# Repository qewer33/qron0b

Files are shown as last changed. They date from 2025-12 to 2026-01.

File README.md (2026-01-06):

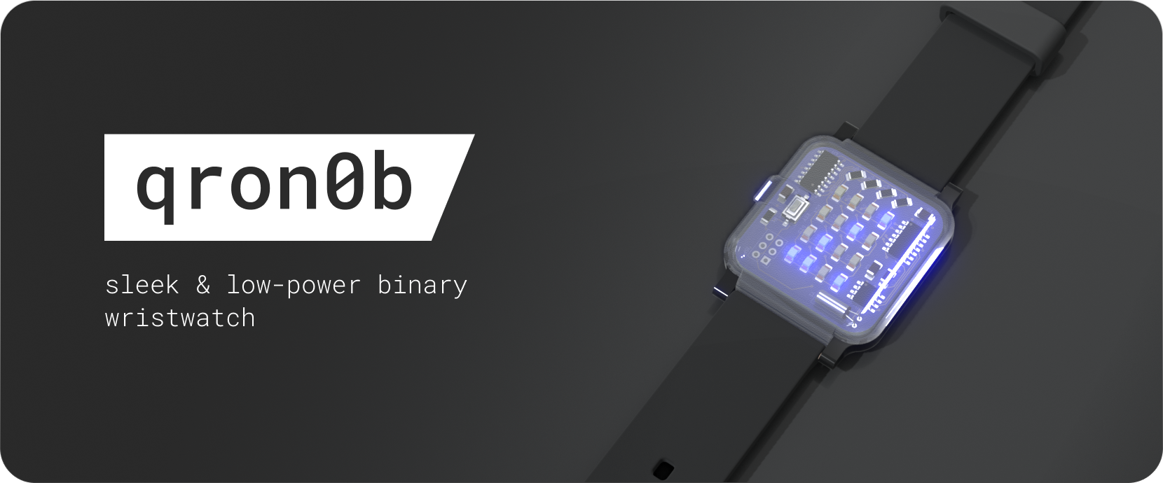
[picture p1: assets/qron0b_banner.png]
banner


**qron0b** is a minimalist and low-power digital **binary wristwatch**. It uses an **Attiny24A/44A/84A as it's MCU**, uses the **DS1302 as it's RTC** and displays the time in **BCD (binary coded decimal)** format with it's integrated **4x4 LED matrix driven by an 74HC595 shift register**. It's powered by a single **CR2032 coin cell battery**. It's designed to use minimal power and **can run without a battery change for months**.

> [!WARNING]  
> This project is NOT perfect by any means, it's my first ever low-power board design and thus contains many design flaws (although mostly small). It does work but build it at your own risk and definitely don't expect everything to go smoothly.

## Repository Layout
- [pcb/](https://github.com/qewer33/qron0b/tree/main/pcb): The KiCAD project for the qron0b PCB.
- [cad/](https://github.com/qewer33/qron0b/tree/main/cad): The FreeCAD files (and .stl + .step for 3D printing) for the watch case.
- [firmware/](https://github.com/qewer33/qron0b/tree/main/firmware): The source code for the qron0b firmware, written in bare metal AVR C.
- [assets/](https://github.com/qewer33/qron0b/tree/main/assets) Screenshots and render files used in the README.

## The Product

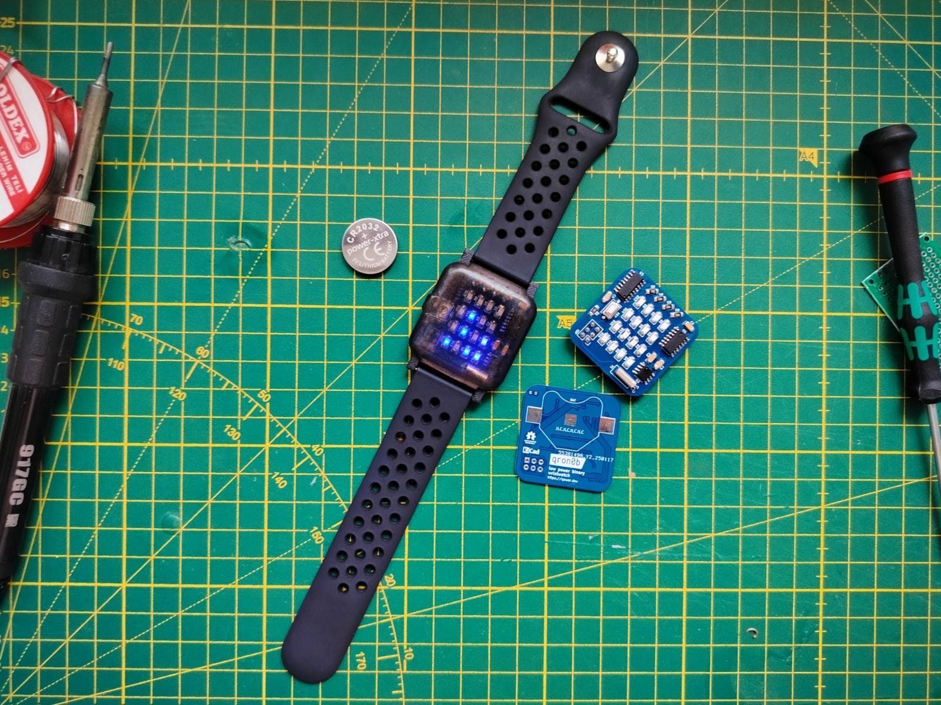
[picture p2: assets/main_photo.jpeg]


### Features

qron0b's default firmware is very minimalistic and thus only contains two basic features: **reading time** and **setting time**. The watch is in the sleep state by default with the CPU in power-down mode and the display off. When the onboard button is clicked, the CPU is wakes up from sleep and displays the current time in the LED matrix for 10 seconds. The time can be set while the watch is awake by long pressing the onboard button. Both features are explained in detail under the next two headings.

### Reading Time

The time is displayed in BCD (binary coded decimal) format on qron0b's 4x4 LED matrix in columns (HH:MM), with the LSB (least-significant bit) being the bottom-most LED. Meaning for each column; the bottom-most LED represents 1, the one above represents 2, two above represents 4 and the top-most LED represents 8. All LEDs being off in a column represents 0. The first column is the tens digit of hour, the second column is the ones digit of hour, third column is the tens digit of minute and the fourth column is the ones digit of minute.

Below is a visual explanation and a few examples to help explain it better:

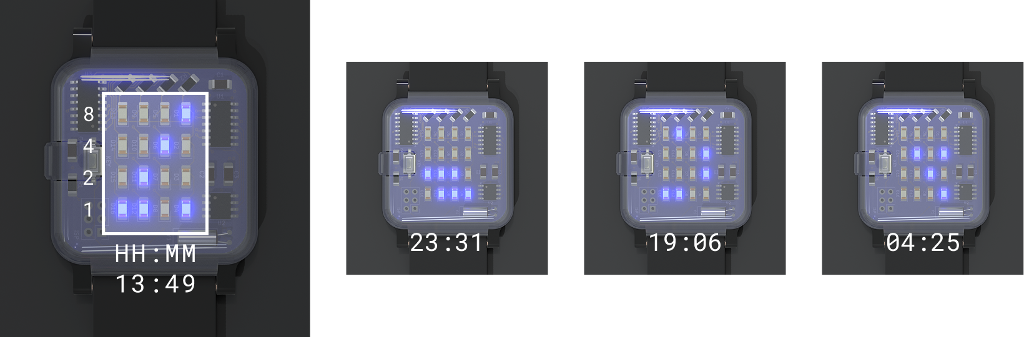
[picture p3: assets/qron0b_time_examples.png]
reading time


### Setting Time

The time can be set while the watch is awake by long pressing the onboard button. The whole LED matrix will flash for ~0.5 seconds to indicate entering edit mode. After the watch enters edit mode, the first column (tens digit of hour) will start flashing (it may not flash if it's 0). Press the button once to increment the current column/digits value (it will wrap automatically, eg. between 0-2 for tens digit of hour or 0-5 for the tens digit of minute). After setting the current digit to the desired value, long press the button to move on to the next digit (the next column will start flashing). Long pressing on the last digit/column (the ones column of minute) will save the newly set time to the RTC and exit edit mode.

## Hardware

### PCB Design

The qron0b PCB is designed in the free and open source EDA software, KiCAD. You can find the PCB design source files under [pcb/](https://github.com/qewer33/qron0b/tree/main/pcb).

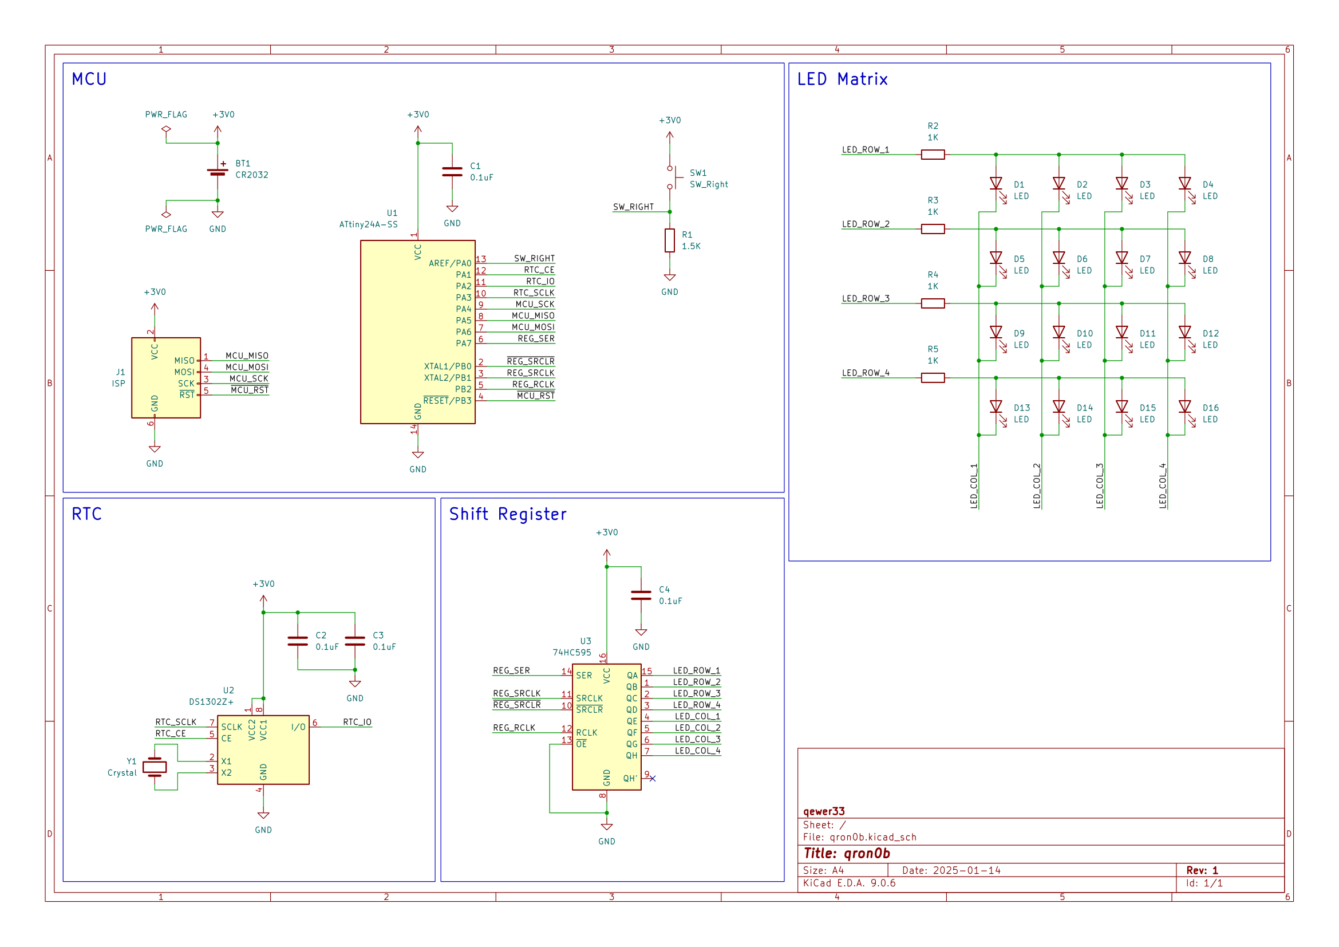
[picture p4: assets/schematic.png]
schematic


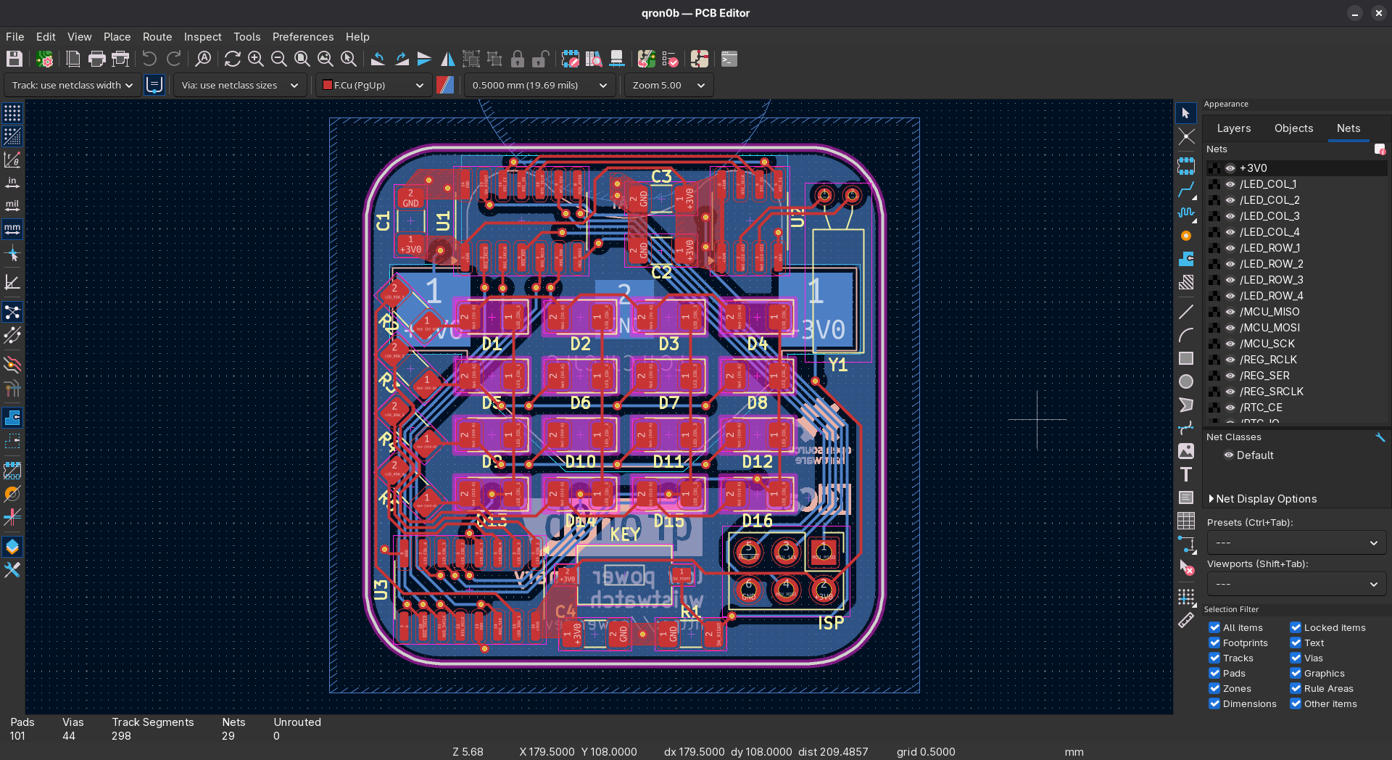
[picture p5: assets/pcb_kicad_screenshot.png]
kicad screenshot


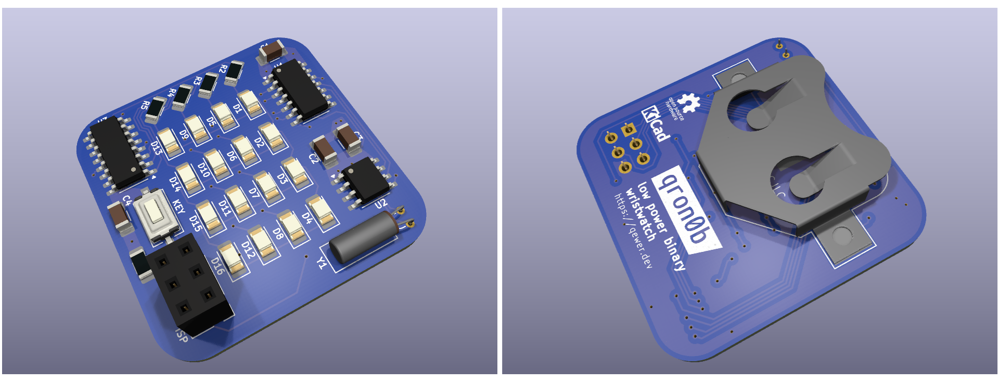
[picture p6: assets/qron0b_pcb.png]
pcb 3d render


### Mechanical Design

The mechanical parts of qron0b (the watch casing) is designed in the free and open source CAD software, FreeCAD. The watch case is designed in 2 parts: the bottom base and the top "glass". They connect together via a simple clip system. The bottom base casing accepts 22mm GT2/GT3 style watch straps.

You can find the CAD source and 3D print files under [cad/](https://github.com/qewer33/qron0b/tree/main/cad).

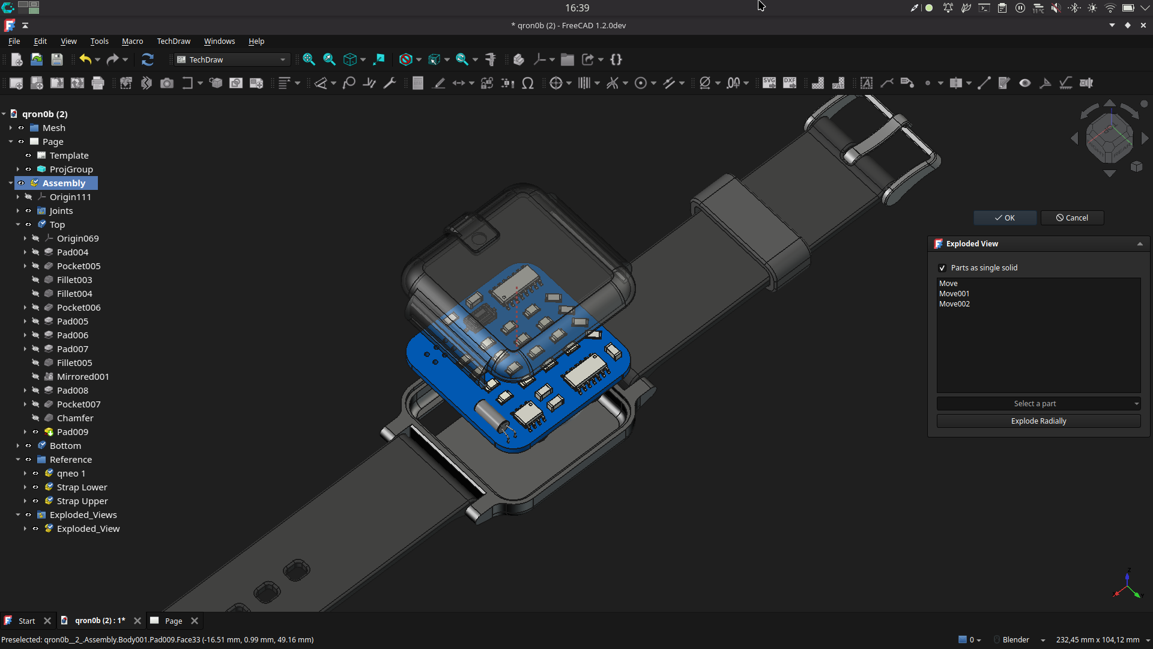
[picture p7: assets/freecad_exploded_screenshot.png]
freecad screenshot


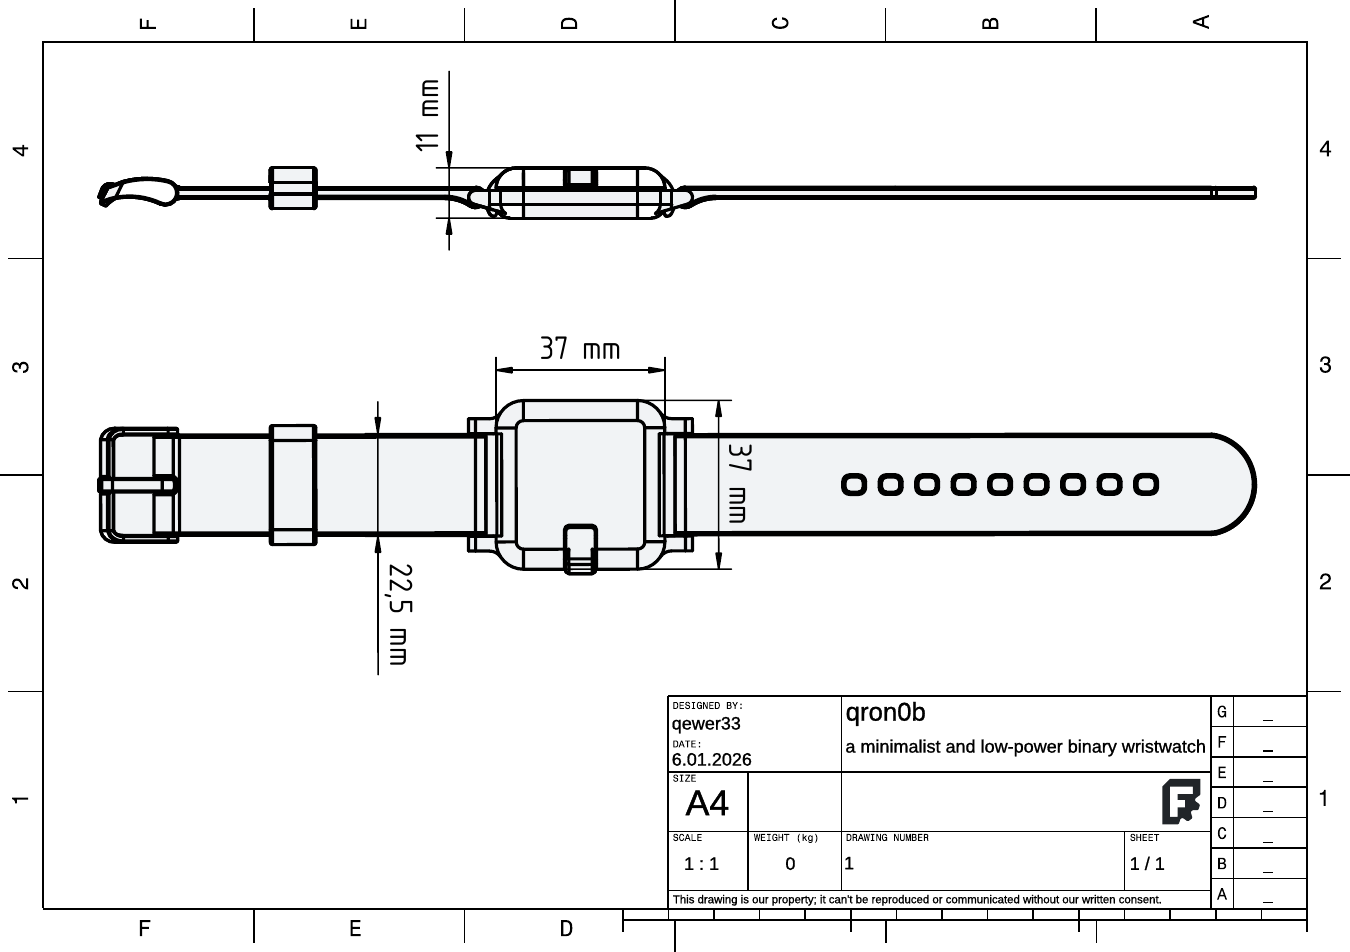
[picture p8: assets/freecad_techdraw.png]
technical drawing


## Firmware

The qron0b firmware is written in bare-metal AVR C. It's written to be as minimal as possible and is only 1916 bytes, meaning it can even run on the ATtiny24A (in fact, it's designed for the 24A!).

For more information on the firmware, see the README.md file inside [firmware/](https://github.com/qewer33/qron0b/tree/main/firmware).

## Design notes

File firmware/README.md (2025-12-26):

# Firmware Architecture

- `main.c`: The main source file, contains firmware entry point and main firmware logic.
- `config.h`: Contains global pin definition macros.
- `gpio.h`: Contains helper GPIO macros.
- `init.h/c`: Contains the startup and initilization routine functions.
- `key.h/c`: Contains functions and definitions related to the onboard button input.
- `matrix.h/c`: Contains shift register read/write functions and higher-level matrix screen interface functions.
- `rtc.h/c`: Contains RTC read/write functions.

# Programming

The qron0b board can be programmed with any AVR ISP programmer (including any AVR Arduino board via Arduino as ISP). You need to have the `avr-gcc` toolchain installed. If you're on Linux, you can use the provided shell scripts to build and flash the firmware.

Use the `make` command to build & flash the firmware. Build artifacts (`.elf`, `.hex` and `.o` files) will be generated in the `build/` directory. Use the `make flash_fuses` command in first flash to set the correct fuses. If programming with Arduino as ISP, put a 10uF cap between the Arduino's RES and GND pins.

```sh
# Build the firmware
make

# Flash firmware and fuses to USB0 (do this for first time flashing!)
make flash_fuses
# Flash firmware only to USB0 (do this after first flash)
make flash

# Specify a different port for flashing
make flash PORT=USB1

# See firmware size
make size

# Clean the build directory
make clean
```

Alternatively, you can also use the provided bash scripts:

Use the provided `build.sh` script to compile & build the firmware.

Use the provided `flasn.sh` script to flash with an Arduino as ISP mounted at USB0 (change the port inside the script if necessary). Use the `--fuses` option in first flash to set the correct fuses.

```sh
# Build the firmware
./build.sh

# Flash the firmware with fuses (do this for first time flashing!)
./flash.sh --fuses
# Flash the firmware without fuses (do this after first flash)
./flash.sh

# Build and flash firmware
./build.sh && ./flash.sh
```

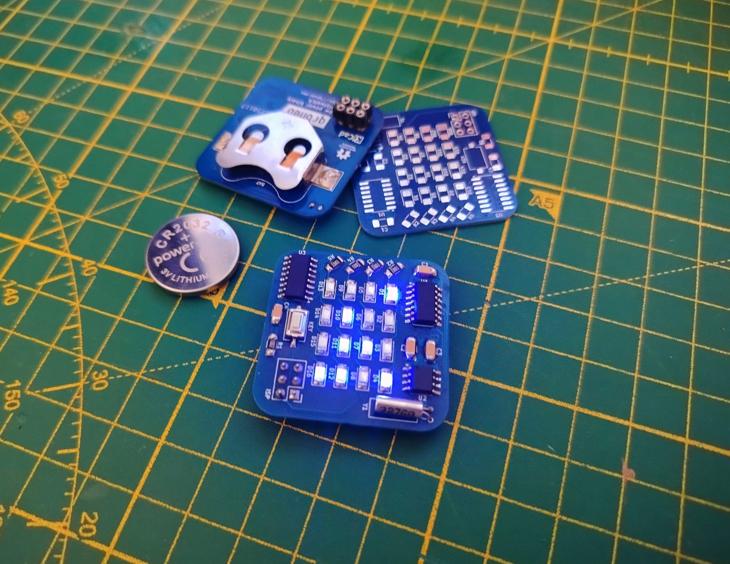
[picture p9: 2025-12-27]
assets/board_photo.jpeg

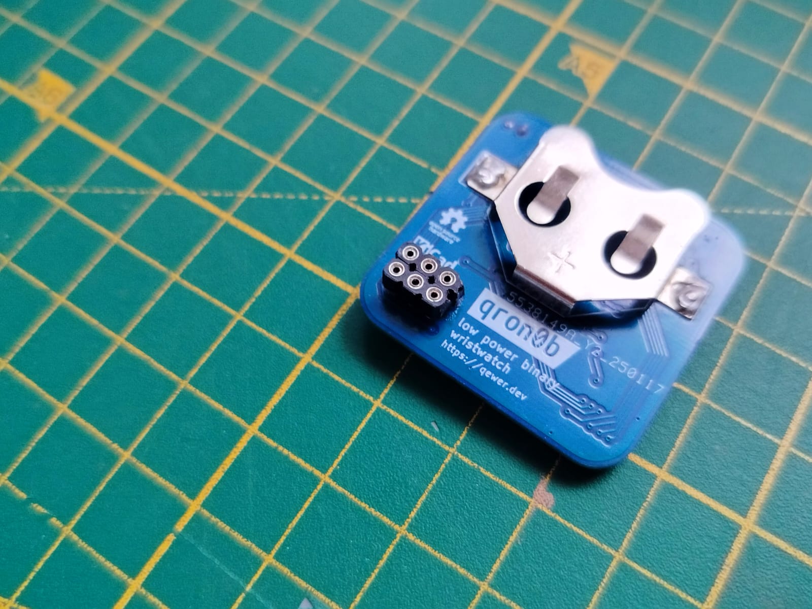
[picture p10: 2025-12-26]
assets/programming_header_photo.jpeg

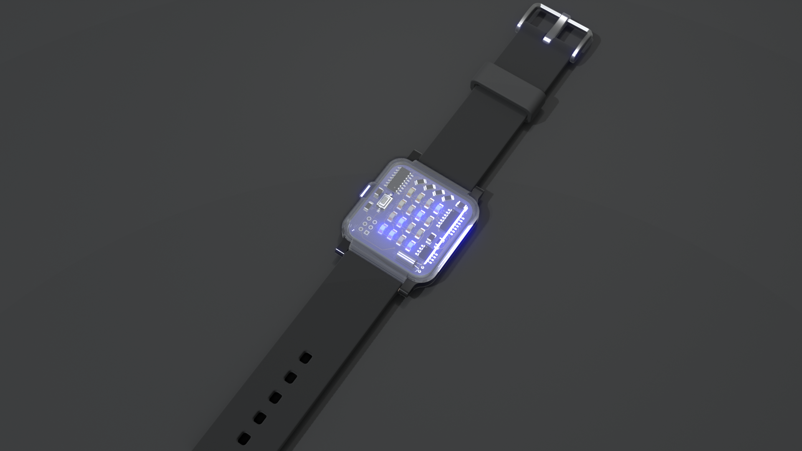
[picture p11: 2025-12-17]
assets/qron0b_render.png

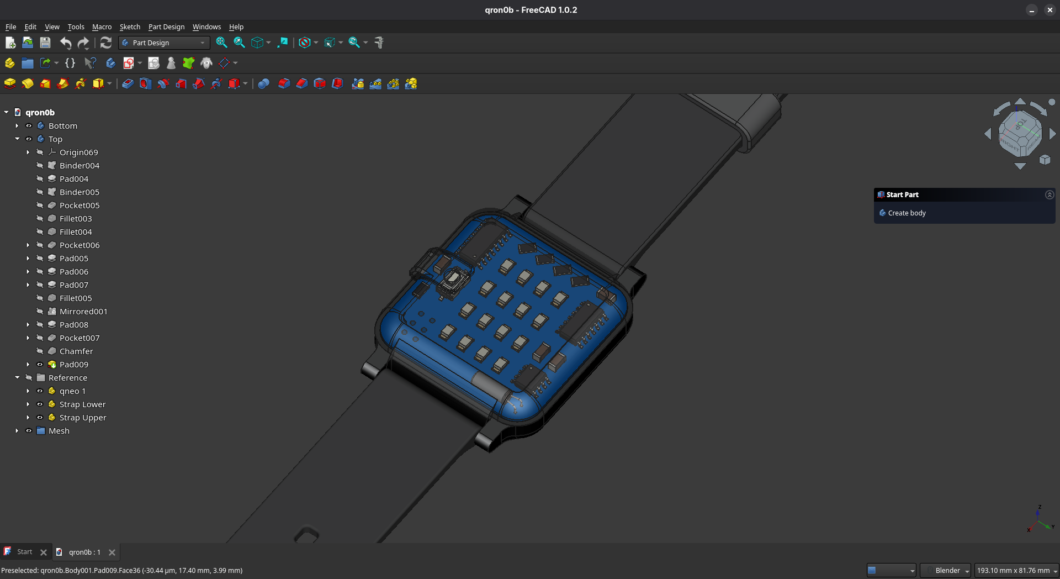
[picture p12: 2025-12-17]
assets/freecad_screenshot.png

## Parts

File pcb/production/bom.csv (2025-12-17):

Designator | Footprint | Quantity | Value | LCSC Part #
BAT | BatteryHolder_Multicomp_BC-2001_1x2032 | 1 | CR2032
C1, C2, C3, C4 | 1206 | 4 | 0.1uF
D1, D10, D11, D12, D13, D14, D15, D16, D2, D3, D4, D5, D6, D7, D8, D9 | 1206 | 16 | LED
ISP | PinHeader_2x03_P2.54mm_Vertical | 1 | ISP
KEY | SW_Tactile_SPST_NO_Straight_CK_PTS636Sx25SMTRLFS | 1 | SW_Right
R1 | 1206 | 1 | 1.5K
R2, R3, R4, R5 | 1206 | 4 | 1K
U1 | SOIC-14_3.9x8.7mm_P1.27mm | 1 | ATtiny24A-SS
U2 | SOIC-8_3.9x4.9mm_P1.27mm | 1 | DS1302Z+
U3 | SOIC-16_3.9x9.9mm_P1.27mm | 1 | 74HC595
Y1 | Crystal_C38-LF_D3.0mm_L8.0mm_Horizontal | 1 | Crystal

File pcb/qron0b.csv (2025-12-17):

Id | Designator | Footprint | Quantity | Designation | Supplier and ref
1 | SW1 | SW_Tactile_SPST_NO_Straight_CK_PTS636Sx25SMTRLFS | 1 | SW_Right
2 | R4,R3,R2,R5 | R_1206_3216Metric_Pad1.30x1.75mm_HandSolder | 4 | 1K
3 | D8,D13,D15,D1,D2,D11,D12,D6,D16,D9,D14,D3,D7,D10,D5,D4 | LED_1206_3216Metric_Pad1.42x1.75mm_HandSolder | 16 | LED
4 | U3 | SOIC-16_3.9x9.9mm_P1.27mm | 1 | 74HC595
5 | C3,C1,C4,C2 | C_1206_3216Metric_Pad1.33x1.80mm_HandSolder | 4 | 0.1uF
6 | U1 | SOIC-14_3.9x8.7mm_P1.27mm | 1 | ATtiny24A-SS
7 | U2 | SOIC-8_3.9x4.9mm_P1.27mm | 1 | DS1302Z+
8 | R1 | R_1206_3216Metric_Pad1.30x1.75mm_HandSolder | 1 | 1.5K

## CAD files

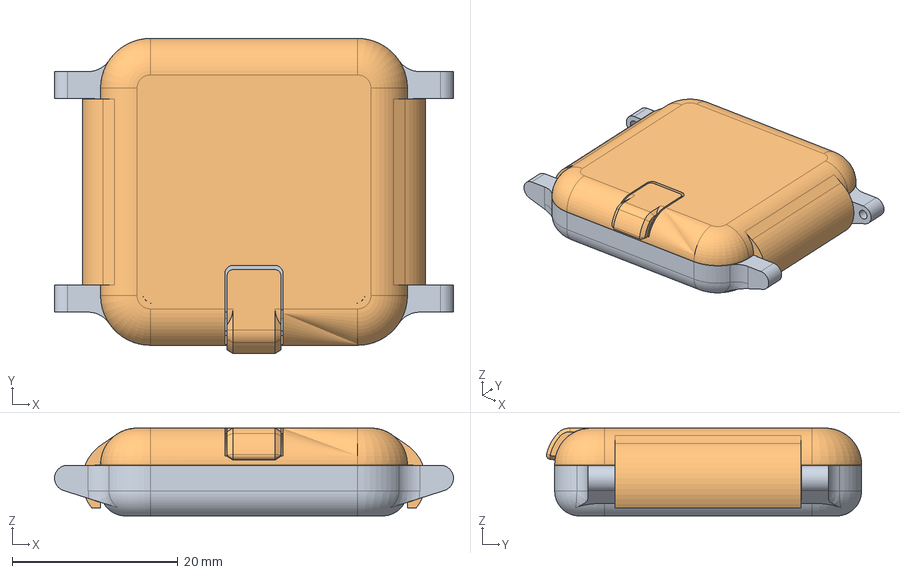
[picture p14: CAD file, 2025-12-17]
cad/qron0b.FCStd
48.1 x 38.0 x 10.6 mm
Bottom
Top

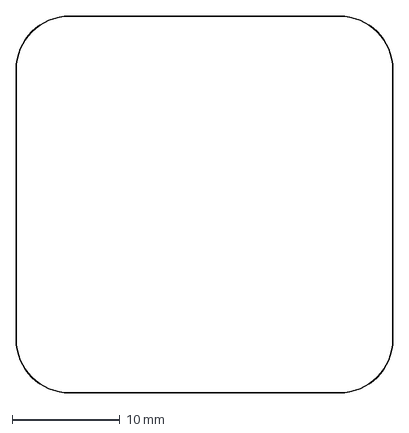
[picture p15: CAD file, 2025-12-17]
pcb/board_outline.dxf
35.0 x 35.0 mm

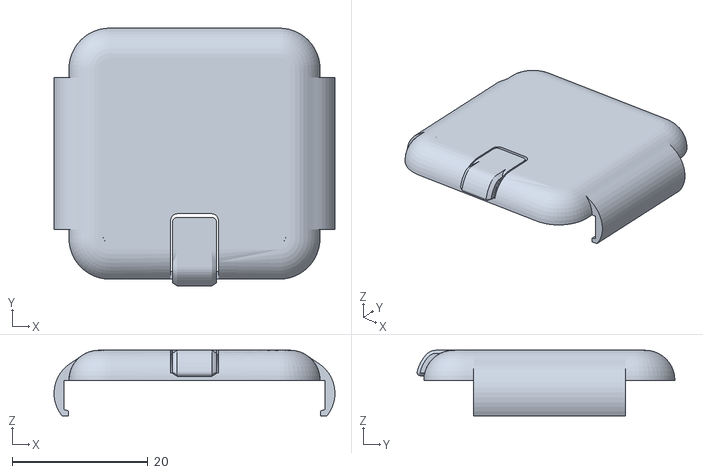
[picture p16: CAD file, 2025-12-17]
cad/qron0b-TopGlass.stl
41.4 x 38.0 x 9.67

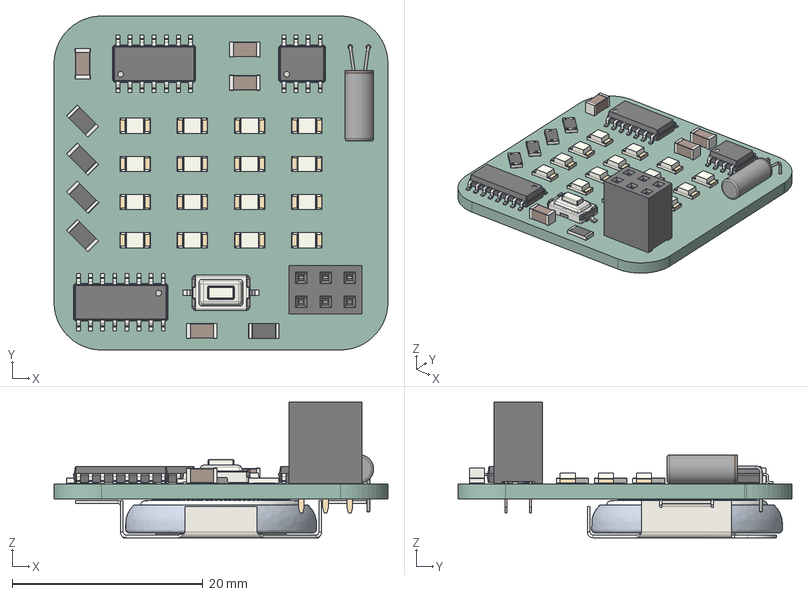
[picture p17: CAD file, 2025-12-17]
pcb/qron0b.step
35.0 x 35.0 x 14.2 mm
PTS636Sx25SMTRLFS
R_1206_3216Metric x 5
LED_1206_3216Metric x 16
SOIC_16_39x99mm_P127mm
PinSocket_2x03_P2.54mm_Vertical
C_1206_3216Metric x 4
SOIC_14_39x87mm_P127mm
C38_LF_Horizontal
SOIC_8_39x49mm_P127mm
RS_PRO_CR2032_CLIP_2378333 v5
Document
_autosave-qneo_PCB

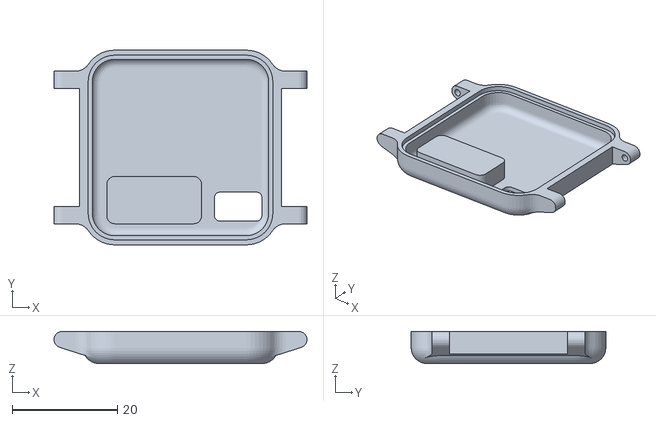
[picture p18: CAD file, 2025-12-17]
cad/qron0b-Bottom.stl
48.1 x 37.0 x 6.10

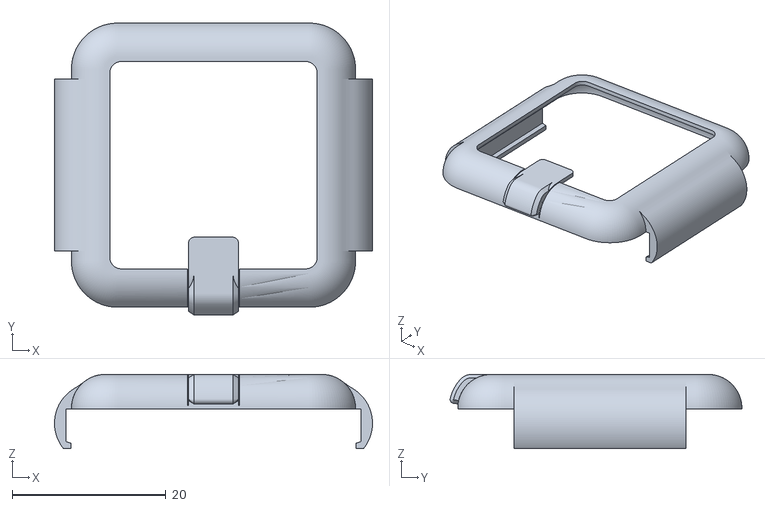
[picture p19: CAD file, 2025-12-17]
cad/qron0b-Top.stl
41.4 x 38.0 x 9.67

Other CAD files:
assets/qron0b.blend

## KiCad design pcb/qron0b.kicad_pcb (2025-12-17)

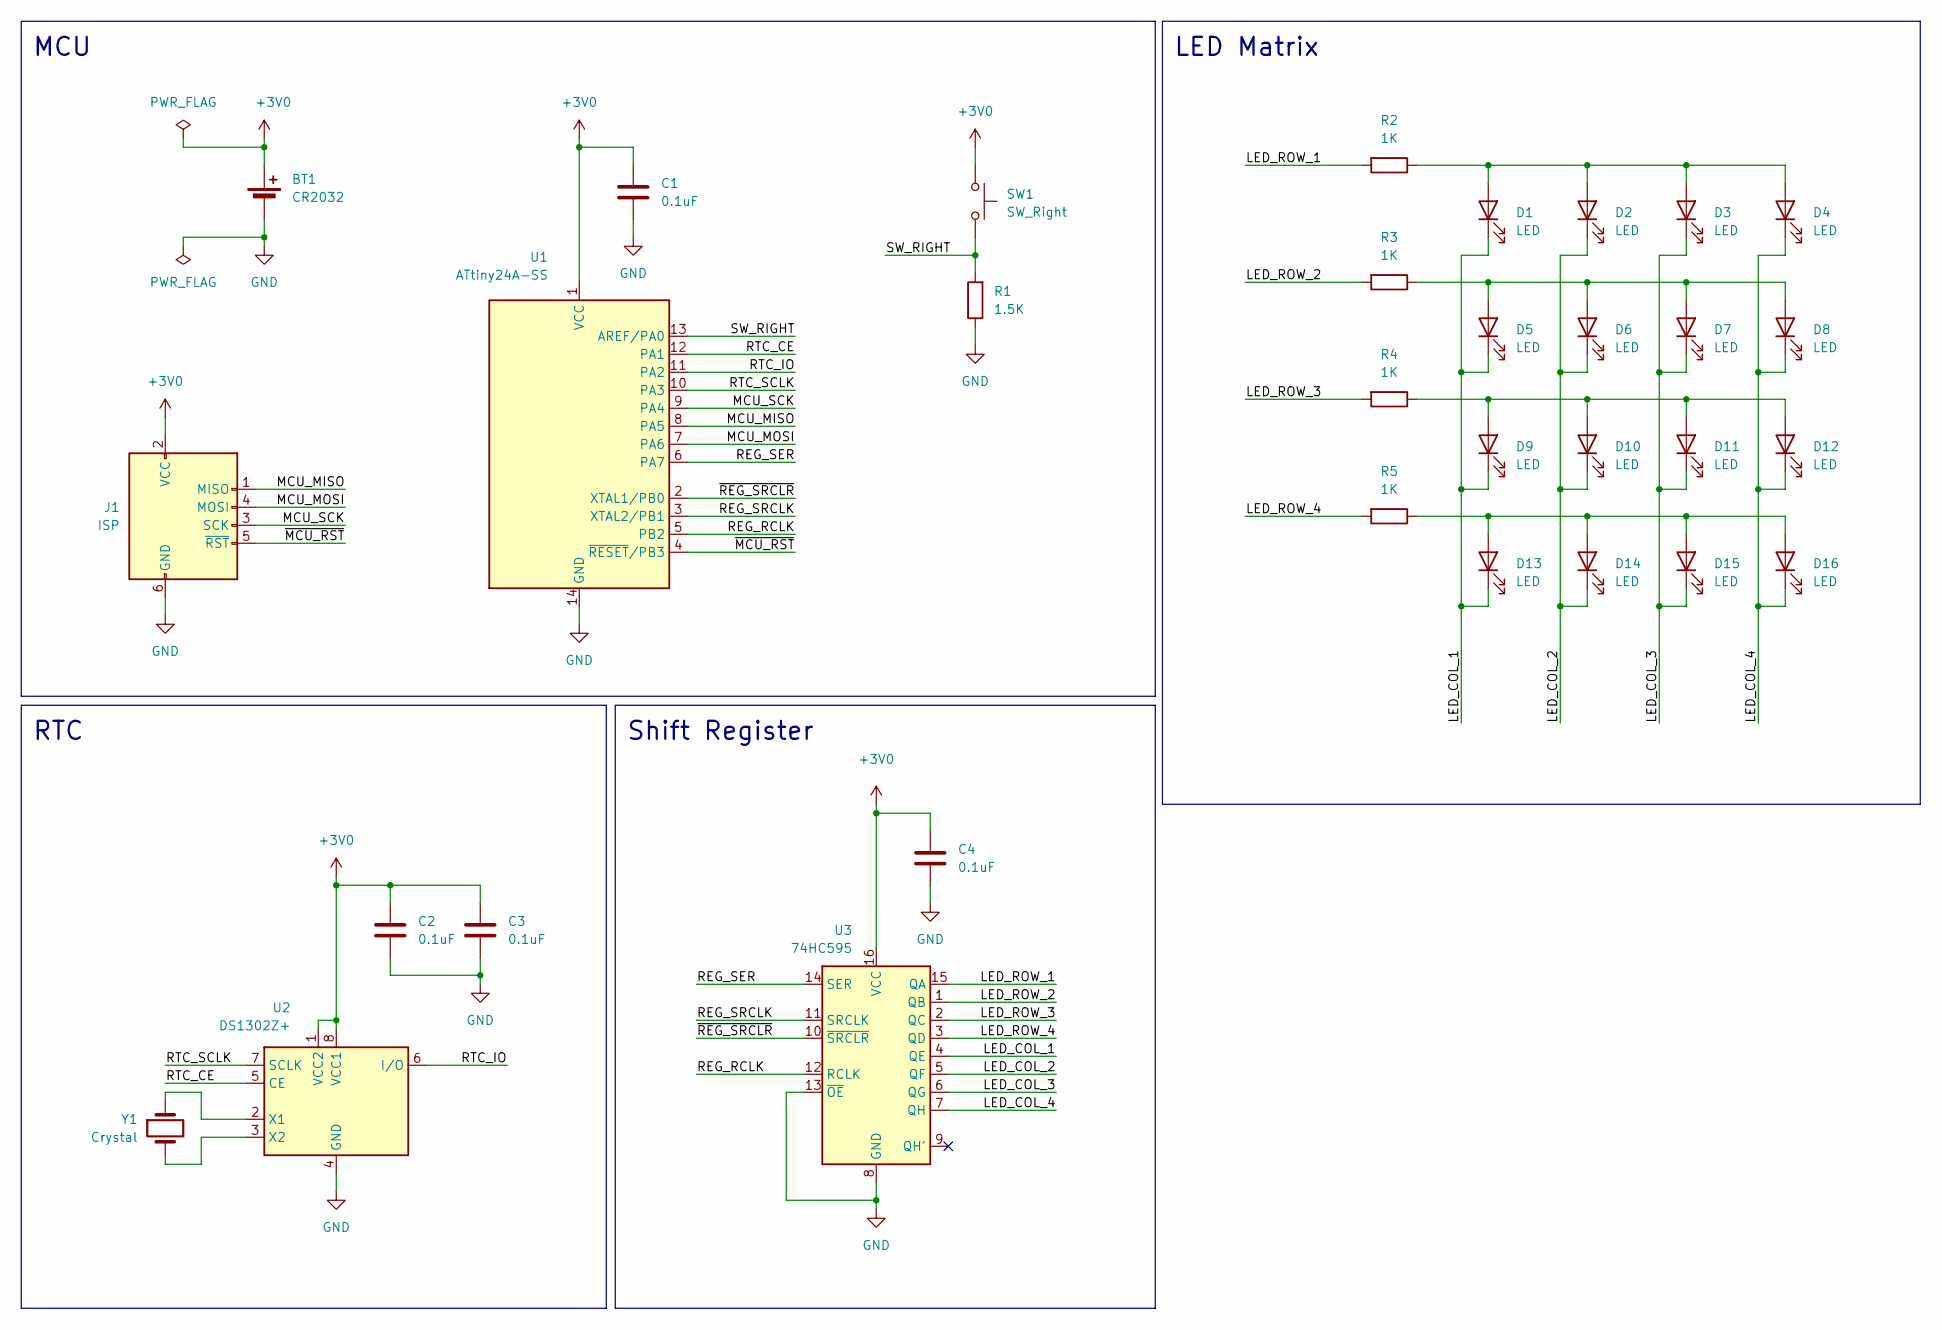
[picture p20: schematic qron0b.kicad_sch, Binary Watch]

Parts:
BT1: CR2032; BatteryHolder_Multicomp_BC-2001_1x2032
C1, C2, C3, C4: 0.1uF; C_1206_3216Metric_Pad1.33x1.80mm_HandSolder
D1, D2, D3, D4, D5, D6, D7, D8, D9, D10, D11, D12, D13, D14, D15, D16: LED; LED_1206_3216Metric_Pad1.42x1.75mm_HandSolder
J1: ISP; PinHeader_2x03_P2.54mm_Vertical
R1: 1.5K; R_1206_3216Metric_Pad1.30x1.75mm_HandSolder
R2, R3, R4, R5: 1K; R_1206_3216Metric_Pad1.30x1.75mm_HandSolder
SW1: SW_Right; SW_Tactile_SPST_NO_Straight_CK_PTS636Sx25SMTRLFS
U1: ATtiny24A-SS; SOIC-14_3.9x8.7mm_P1.27mm
U2: DS1302Z+; SOIC-8_3.9x4.9mm_P1.27mm
U3: 74HC595; SOIC-16_3.9x9.9mm_P1.27mm
Y1: Crystal; Crystal_C38-LF_D3.0mm_L8.0mm_Horizontal

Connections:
+3V0: BT1.1 (+), C1.1, C2.1, C3.1, C4.1, J1.2 (VCC), SW1.2, U1.1 (VCC), U2.1 (VCC2), U2.8 (VCC1), U3.16 (VCC); also elsewhere on the board
/LED_COL_1: D1.1 (K), D5.1 (K), D9.1 (K), D13.1 (K), U3.4 (QE)
/LED_COL_2: D2.1 (K), D6.1 (K), D10.1 (K), D14.1 (K), U3.5 (QF)
/LED_COL_3: D3.1 (K), D7.1 (K), D11.1 (K), D15.1 (K), U3.6 (QG)
/LED_COL_4: D4.1 (K), D8.1 (K), D12.1 (K), D16.1 (K), U3.7 (QH)
/LED_ROW_1: R2.2, U3.15 (QA)
/LED_ROW_2: R3.2, U3.1 (QB)
/LED_ROW_3: R4.2, U3.2 (QC)
/LED_ROW_4: R5.2, U3.3 (QD)
/MCU_MISO: J1.1 (MISO), U1.8 (PA5); also elsewhere on the board
/MCU_MOSI: J1.4 (MOSI), U1.7 (PA6); also elsewhere on the board
/MCU_SCK: J1.3 (SCK), U1.9 (PA4); also elsewhere on the board
/REG_RCLK: U1.5 (PB2), U3.12 (RCLK)
/REG_SER: U1.6 (PA7), U3.14 (SER)
/REG_SRCLK: U1.3 (XTAL2/PB1), U3.11 (SRCLK)
/RTC_CE: U1.12 (PA1), U2.5 (CE)
/RTC_IO: U1.11 (PA2), U2.6 (I/O)
/RTC_SCLK: U1.10 (PA3), U2.7 (SCLK)
/SW_RIGHT: R1.2, SW1.1, U1.13 (AREF/PA0); also elsewhere on the board
/~MCU_RST: J1.5 (~RST), U1.4 (~RESET/PB3); also elsewhere on the board
/~REG_SRCLR: U1.2 (XTAL1/PB0), U3.10 (~SRCLR)
GND: BT1.2 (-), C1.2, C2.2, C3.2, C4.2, J1.6 (GND), R1.1, U1.14 (GND), U2.4 (GND), U3.8 (GND), U3.13 (~OE); also elsewhere on the board
unnamed: D1.2 (A), D2.2 (A), D3.2 (A), D4.2 (A), R2.1
unnamed: D5.2 (A), D6.2 (A), D7.2 (A), D8.2 (A), R3.1
unnamed: D9.2 (A), D10.2 (A), D11.2 (A), D12.2 (A), R4.1
unnamed: D13.2 (A), D14.2 (A), D15.2 (A), D16.2 (A), R5.1
unnamed: U2.2 (X1), Y1.1
unnamed: U2.3 (X2), Y1.2

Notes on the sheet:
Shift Register
MCU
LED Matrix
RTC

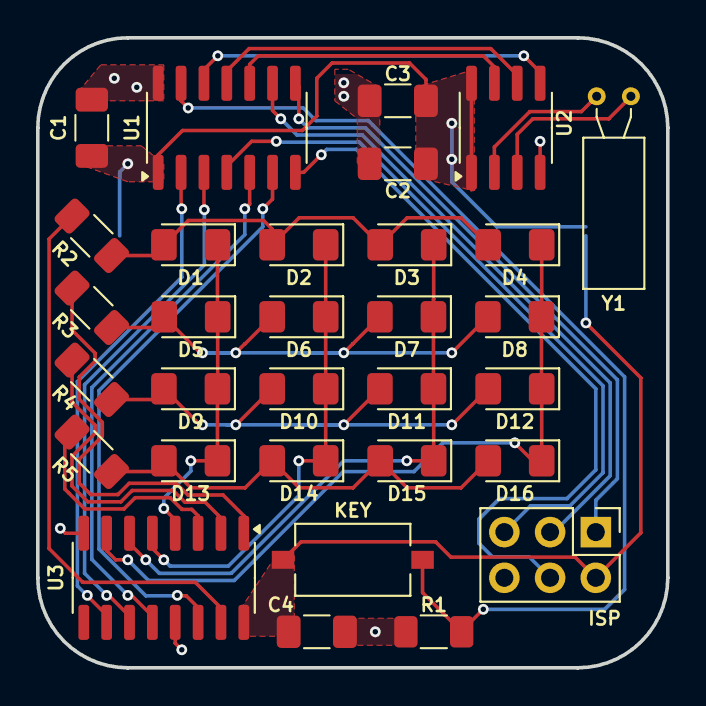
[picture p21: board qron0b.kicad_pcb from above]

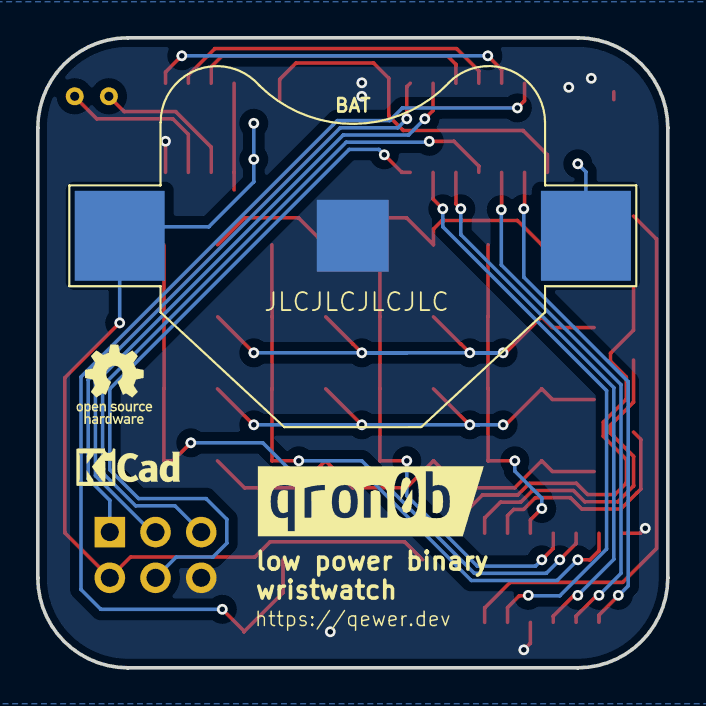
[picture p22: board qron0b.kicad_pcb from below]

Board: 2 copper layers, 35.0 x 35.0 mm, 33 parts (2 on the bottom side), 28 nets.

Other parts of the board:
BAT: CR2032; BatteryHolder_Multicomp_BC-2001_1x2032
ISP: ISP; PinHeader_2x03_P2.54mm_Vertical
KEY: SW_Right; SW_Tactile_SPST_NO_Straight_CK_PTS636Sx25SMTRLFS
kibuzzard-678832A4: G***; kibuzzard-678832A4

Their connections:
+3V0: BAT.1 (+), ISP.2 (VCC), KEY.2; also elsewhere on the board
/MCU_MISO: ISP.1 (MISO); also elsewhere on the board
/MCU_MOSI: ISP.4 (MOSI); also elsewhere on the board
/MCU_SCK: ISP.3 (SCK); also elsewhere on the board
/SW_RIGHT: KEY.1; also elsewhere on the board
/~MCU_RST: ISP.5 (~RST); also elsewhere on the board
GND: BAT.2 (-), ISP.6 (GND); also elsewhere on the board

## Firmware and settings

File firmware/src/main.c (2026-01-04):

#include "init.h"
#include "matrix.h"
#include "rtc.h"
#include "key.h"

#include <avr/eeprom.h>
#include <avr/io.h>
#include <avr/interrupt.h>
#include <util/delay.h>
#include <avr/wdt.h>

// Flag to set comptime only on first boot after flash
#define COMPTIME_FLAG_ADDR 0x00

// Global variable to track system uptime (in ms)
volatile uint16_t uptime = 0;

// Watch state management
typedef enum {
    STATE_DISPLAY,
    STATE_EDIT
} State;

static State state = STATE_DISPLAY;
static uint8_t h, m, s;

// Edit mode management
typedef enum {
    EDIT_HOUR_TENS,
    EDIT_HOUR_ONES,
    EDIT_MINUTE_TENS,
    EDIT_MINUTE_ONES,
} EditMode;

static EditMode edit_mode = EDIT_HOUR_TENS;
static uint8_t edit_h = 0;
static uint8_t edit_m = 0;
static void state_display(void);
static void state_edit(KeyEvent key_ev);

int main(void) {
    MCUSR = 0;
    wdt_disable();
        
    // Hardware init
    disable_unused();
    setup_wakeup_pin();
    shift_register_init();
    rtc_init();
    timer_init();
    
    // Enable watchdog timer
    wdt_enable(WDTO_2S);

    sei(); // Enable interrupts

    // Use compile time clock only after first flash
    if (eeprom_read_byte(COMPTIME_FLAG_ADDR) == 0xFF) {
        get_compile_time(&h, &m, &s);
        rtc_set_time(h, m, s);
        // Update flag
        eeprom_update_byte(COMPTIME_FLAG_ADDR, 0x00);
    }

    wdt_reset();
    
    // Main loop
    while (1) {
        wdt_reset();
        
        KeyEvent key_ev = read_key(uptime);

        // Switch to edit mode if key long pressed on display mode
        if (state == STATE_DISPLAY && key_ev == KEY_LONG_PRESS) {
            // Consume key event
            key_ev = KEY_NONE;

            // Switch mode and state
            edit_mode = EDIT_HOUR_TENS;
            state = STATE_EDIT;

            // Initialize edit buffers
            edit_h = h;
            edit_m = m;

            // Visual cue for edit mode enter
            matrix_all_on();
            _delay_ms(500);
            matrix_all_off();
            _delay_ms(250);
        }

        switch (state) {
            case STATE_DISPLAY:
                state_display();
            break;
            case STATE_EDIT:
                state_edit(key_ev);
            break;
        }
    }
}

// Display state
static void state_display(void) {
    // Show display for 10 seconds (10000 ms)
    if (uptime < 10000) {
        // Refresh time each second
        if (uptime % 1000 == 0) {
            rtc_get_time(&h, &m, &s);
        }

        matrix_display_time(h, m);

        _delay_us(600); // Idle between frames to cut average LED load
    } else {
        wdt_disable(); // Disable WDT
        enter_deep_sleep();
        // After sleep
        wdt_enable(WDTO_2S); // Re-enable WDT
        rtc_get_time(&h, &m, &s);
        uptime = 0;
    }
}

// Edit state
static void state_edit(KeyEvent key_ev) {
    switch (edit_mode) {
        // Editing first digit of hour
        case EDIT_HOUR_TENS:
            if (key_ev == KEY_PRESS) {
                uint8_t tens = edit_h / 10;
                tens = (tens + 1) % 3; // 0-2
                if (tens == 2 && (edit_h % 10) > 3) {
                    edit_h = 23;
                } else {
                    edit_h = tens * 10 + (edit_h % 10);
                }
            }

            matrix_blink_time(edit_h, edit_m, 0, uptime);

            if (key_ev == KEY_LONG_PRESS) edit_mode = EDIT_HOUR_ONES;
            break;

        // Editing second digit of hour
        case EDIT_HOUR_ONES:
            if (key_ev == KEY_PRESS) {
                uint8_t tens = edit_h / 10;
                uint8_t ones = edit_h % 10;
                ones = (ones + 1) % 10;
                if (tens == 2 && ones > 3) ones = 0;
                edit_h = tens * 10 + ones;
            }

            matrix_blink_time(edit_h, edit_m, 1, uptime);

            if (key_ev == KEY_LONG_PRESS) edit_mode = EDIT_MINUTE_TENS;
            break;

        // Editing first digit of minute
        case EDIT_MINUTE_TENS:
            if (key_ev == KEY_PRESS) {
                uint8_t tens = edit_m / 10;
                tens = (tens + 1) % 6; // 0-5
                edit_m = tens * 10 + (edit_m % 10);
            }

            matrix_blink_time(edit_h, edit_m, 2, uptime);

            if (key_ev == KEY_LONG_PRESS) edit_mode = EDIT_MINUTE_ONES;
            break;

        // Editing second digit of minute
        case EDIT_MINUTE_ONES:
            if (key_ev == KEY_PRESS) {
                uint8_t tens = edit_m / 10;
                uint8_t ones = edit_m % 10;
                ones = (ones + 1) % 10;
                edit_m = tens * 10 + ones;
            }

            matrix_blink_time(edit_h, edit_m, 3, uptime);

            // Save new time to RTC and return to display state
            if (key_ev == KEY_LONG_PRESS) {
                rtc_set_time(edit_h, edit_m, 0);
                h = edit_h;
                m = edit_m;
                s = 0;
                state = STATE_DISPLAY;
            }
            break;
    }

    _delay_us(600); // Idle between frames to cut average LED load
}

// Wakeup interrupt
ISR(PCINT0_vect) {}

// TIM1 interrupt
ISR(TIM1_COMPA_vect) {
    uptime++;
}

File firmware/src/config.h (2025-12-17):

#pragma once

#define F_CPU 1000000UL // 1 MHz clock

// Pin definitions
#define KEY PA0

// Shift register pins
#define REG_SER PA7
#define REG_SRCLK PB1
#define REG_RCLK PB2
#define REG_SRCLR PB0

// RTC pins
#define RTC_CE PA1
#define RTC_SCLK PA3
#define RTC_IO PA2

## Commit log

2025-12-27 Firmware: Tweak init.c for power saving
2025-12-27 Assets: Add board photo
